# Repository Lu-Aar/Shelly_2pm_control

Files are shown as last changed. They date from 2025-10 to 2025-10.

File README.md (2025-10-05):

# Shelly_2pm_control

This piece of code is designed to be run on a ESP32 Super Mini.
It is able to search for a SHELLY 2PM by looking for its MAC address. It can then control certain features of it.

For now it's only able to:
- Raise the shutter
- Stop the shutter
- Close the shutter
- Put the shutter on ventilation when it's stopped

When checking out there is one file missing "config.h". This file must be created after checking out and it should contain the following two items:
```c
#define WIFI_SSID "THE_SSID_TO_CONNECT_TO"
#define WIFI_PASS "THE_PASSWORD_FOR_THAT_SSID"
```

## PCB
The PCB was created in KiCad. It's a free opensource program for creating schematics and PCB's.
https://www.kicad.org/

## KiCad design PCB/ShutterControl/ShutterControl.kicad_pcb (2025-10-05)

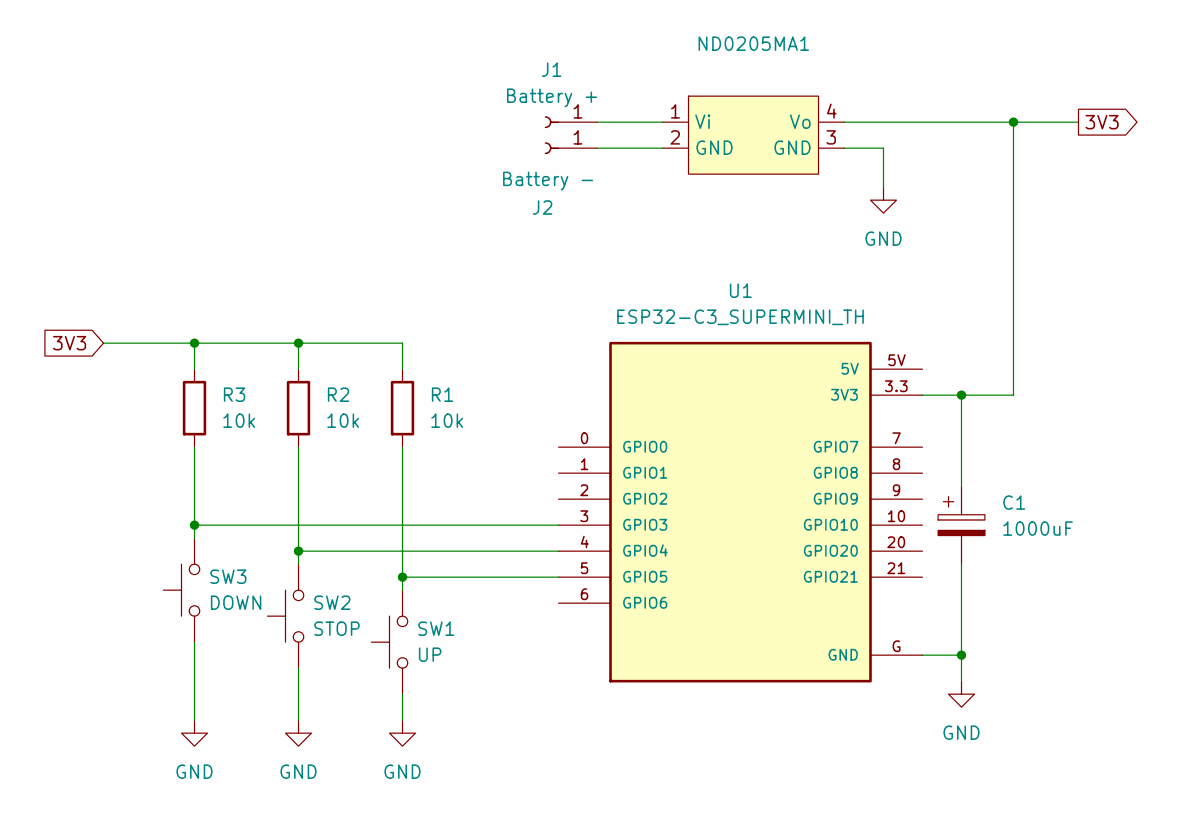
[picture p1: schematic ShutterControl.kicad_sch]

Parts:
C1: 1000uF; CP_Radial_D8.0mm_P3.50mm
J1: Battery +; TestPoint_THTPad_2.0x2.0mm_Drill1.0mm
J2: Battery -; TestPoint_THTPad_2.0x2.0mm_Drill1.0mm
ND0205MA1: ND0205MA
R1, R2, R3: 10k; R_Axial_DIN0204_L3.6mm_D1.6mm_P5.08mm_Horizontal
SW1: UP; SW_PUSH_6mm_H5mm
SW2: STOP; SW_PUSH_6mm_H5mm
SW3: DOWN; SW_PUSH_6mm_H5mm
U1: ESP32-C3_SUPERMINI_TH; MODULE_ESP32-C3_SUPERMINI_TH

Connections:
3V3: C1.1, ND0205MA1.4 (Vo), R1.1, R2.1, R3.1, U1.3.3 (3V3); also elsewhere on the board
GND: C1.2, ND0205MA1.3 (GND), SW1.1, SW2.1, SW3.1, U1.G (GND); also elsewhere on the board
unnamed 2: J1.1, ND0205MA1.1 (Vi); also elsewhere on the board
unnamed 3: J2.1, ND0205MA1.2 (GND); also elsewhere on the board
unnamed: R3.2, SW3.2, U1.3 (GPIO3)
unnamed: R2.2, SW2.2, U1.4 (GPIO4)
unnamed: R1.2, SW1.2, U1.5 (GPIO5)

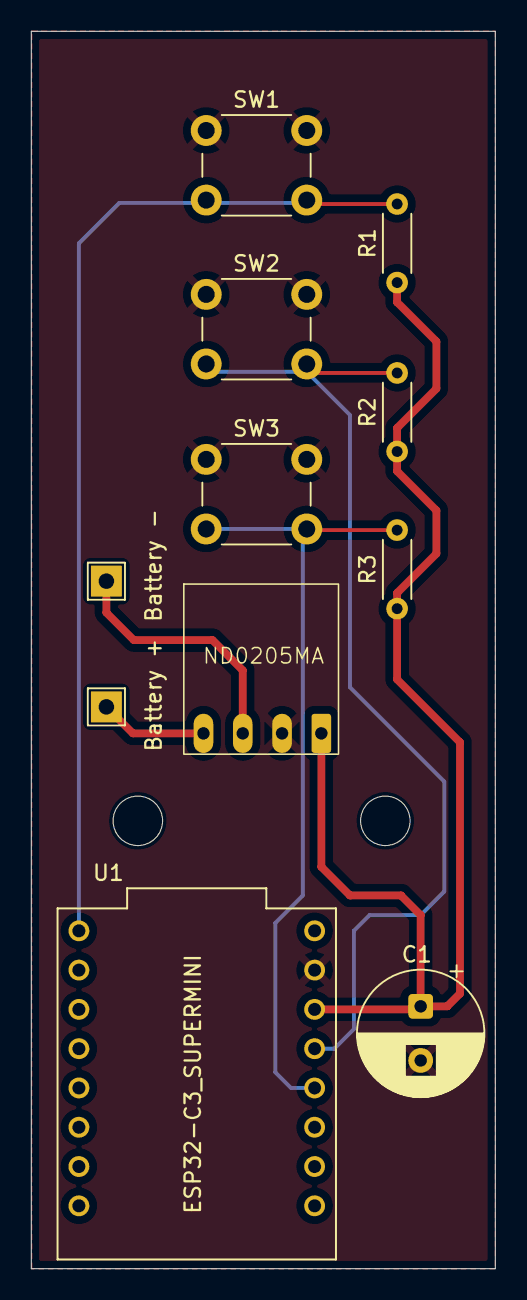
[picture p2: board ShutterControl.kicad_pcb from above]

Board: 2 copper layers, 30.0 x 80.0 mm, 11 parts (0 on the bottom side), 7 nets.

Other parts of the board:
ND0205MA: ND0205MA

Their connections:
3V3: ND0205MA.4 (Vo); also elsewhere on the board
GND: ND0205MA.3 (GND); also elsewhere on the board
unnamed 2: ND0205MA.1 (Vi); also elsewhere on the board
unnamed 3: ND0205MA.2 (GND); also elsewhere on the board

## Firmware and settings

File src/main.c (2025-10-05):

#include <string.h>
#include "esp_system.h"
#include "esp_wifi.h"
#include "esp_event.h"
#include "esp_log.h"
#include "esp_http_client.h"
#include "esp_sleep.h"
#include "esp_pm.h"
#include "nvs_flash.h"
#include "freertos/FreeRTOS.h"
#include "freertos/task.h"
#include "freertos/event_groups.h"
#include "lwip/etharp.h"
#include "lwip/ip_addr.h"
#include "lwip/netif.h"
#include "driver/gpio.h"
#include "soc/gpio_reg.h"
#include "soc/io_mux_reg.h"
#include "ShutterControl.h"
#include "config.h"

// #define DEBUG
struct netif *esp_netif_get_netif_impl(esp_netif_t *esp_netif);

#define ESP_MAXIMUM_RETRY 10

#define WIFI_CONNECTED_BIT BIT0
#define WIFI_FAIL_BIT BIT1
#define ESP_WIFI_SCAN_AUTH_MODE_THRESHOLD WIFI_AUTH_WPA2_PSK

#define START_IP 1
#define END_IP 254

#define BUTTON_UP GPIO_NUM_5
#define BUTTON_STOP GPIO_NUM_4
#define BUTTON_DOWN GPIO_NUM_3

#define MACSTR "%02x:%02x:%02x:%02x:%02x:%02x"

#define AWAKE_TIME_MS 20000

static EventGroupHandle_t s_wifi_event_group;
static int s_retry_num = 0;

const uint8_t SHUTTER_MAC_1[] = {0xE4, 0xB3, 0x23, 0x23, 0x4B, 0x1C};
const uint8_t SHUTTER_MAC_2[] = {0xE4, 0xB3, 0x23, 0x1F, 0xFA, 0xAC};

void init(void);

static void event_handler(void *arg, esp_event_base_t event_base,
                          int32_t event_id, void *event_data)
{
    if (event_base == WIFI_EVENT && event_id == WIFI_EVENT_STA_START)
    {
        esp_wifi_connect();
    }
    else if (event_base == WIFI_EVENT && event_id == WIFI_EVENT_STA_DISCONNECTED)
    {
        if (s_retry_num < ESP_MAXIMUM_RETRY)
        {
            esp_wifi_connect();
            s_retry_num++;
#ifdef DEBUG
            ESP_LOGI("WIFI", "retry to connect to the AP");
#endif
        }
        else
        {
            xEventGroupSetBits(s_wifi_event_group, WIFI_FAIL_BIT);
        }
#ifdef DEBUG
        ESP_LOGI("WIFI", "connect to the AP fail");
#endif
    }
    else if (event_base == IP_EVENT && event_id == IP_EVENT_STA_GOT_IP)
    {
        ip_event_got_ip_t *event = (ip_event_got_ip_t *)event_data;
#ifdef DEBUG
        ESP_LOGI("WIFI", "got ip:" IPSTR, IP2STR(&event->ip_info.ip));
#endif
        s_retry_num = 0;
        xEventGroupSetBits(s_wifi_event_group, WIFI_CONNECTED_BIT);
    }
}

void DisableUnusedPins(void)
{
    gpio_config_t io_conf_0 = {
        .intr_type = GPIO_INTR_DISABLE,
        .mode = GPIO_MODE_OUTPUT,
        .pin_bit_mask = (1ULL << GPIO_NUM_0),
    };
    gpio_config(&io_conf_0);
    gpio_set_level(GPIO_NUM_0, 0);

    gpio_config_t io_conf_rest = {
        .intr_type = GPIO_INTR_DISABLE,
        .mode = GPIO_MODE_INPUT,
        .pin_bit_mask = (1ULL << GPIO_NUM_1) |
                        (1ULL << GPIO_NUM_2) |
                        (1ULL << GPIO_NUM_6) |
                        (1ULL << GPIO_NUM_7) |
                        (1ULL << GPIO_NUM_8) |
                        (1ULL << GPIO_NUM_9) |
                        (1ULL << GPIO_NUM_10) |
                        (1ULL << GPIO_NUM_20) |
                        (1ULL << GPIO_NUM_21),
        .pull_up_en = GPIO_PULLUP_ENABLE,
        .pull_down_en = GPIO_PULLDOWN_DISABLE,
    };
    gpio_config(&io_conf_rest);
}

ip4_addr_t RequestIp(const uint8_t *shutter_mac)
{
    ip4_addr_t result_ip;
    IP4_ADDR(&result_ip, 255, 255, 255, 255);

    esp_netif_t *netif = esp_netif_get_handle_from_ifkey("WIFI_STA_DEF");
    esp_netif_ip_info_t ip_info;
    esp_netif_get_ip_info(netif, &ip_info);

    struct netif *lwip_netif = esp_netif_get_netif_impl(netif);

    for (int ii = START_IP; ii <= END_IP; ++ii)
    {
        ip4_addr_t target_ip;
        IP4_ADDR(&target_ip,
                 ip_info.ip.addr & 0xFF,
                 (ip_info.ip.addr >> 8) & 0xFF,
                 (ip_info.ip.addr >> 16) & 0xFF,
                 ii);

        if (etharp_request(lwip_netif, &target_ip) != ERR_OK)
        {
#ifdef DEBUG
            ESP_LOGI("SHUTTER", "etharp_request failed for IP: " IPSTR, IP2STR(&target_ip));
#endif
        }
        vTaskDelay(pdMS_TO_TICKS(50));

        if ((ii % 10 == 0) || (ii == END_IP - 1))
        {
            struct eth_addr *mac;
            struct netif *netif_out;
            ip4_addr_t *ip_out;

            for (int jj = 0; jj < 10; ++jj)
            {
                if (etharp_get_entry(jj, &ip_out, &netif_out, &mac))
                {
                    if (memcmp(mac->addr, shutter_mac, 6) == 0)
                    {
#ifdef DEBUG
                        ESP_LOGI("SHUTTER", "Found MAC: " MACSTR " for IP: " IPSTR,
                                 mac->addr[0], mac->addr[1], mac->addr[2], mac->addr[3], mac->addr[4], mac->addr[5], IP2STR(ip_out));
#endif
                        return *ip_out;
                        break;
                    }
                }
            }
        }
    }
    return result_ip;
}

void ESPSleep(void)
{
#ifdef DEBUG
    ESP_LOGI("SLEEP", "Going to sleep now");
#endif
    DisableUnusedPins();
    esp_wifi_stop();
    esp_wifi_deinit();
    esp_deep_sleep_start();
}

void setup_wakeup()
{
    const uint64_t wakeup_pins = 1 << BUTTON_UP | 1 << BUTTON_STOP | 1 << BUTTON_DOWN;
    esp_deep_sleep_enable_gpio_wakeup(wakeup_pins, ESP_GPIO_WAKEUP_GPIO_LOW);
}

void GetIps(ip4_addr_t *pShutter1_ip, ip4_addr_t *pShutter2_ip)
{
    nvs_handle_t handle;
    nvs_open("storage", NVS_READWRITE, &handle);
    esp_err_t err1 = nvs_get_u32(handle, "ip1", &pShutter1_ip->addr);
    esp_err_t err2 = nvs_get_u32(handle, "ip2", &pShutter2_ip->addr);
    if (err1 == ESP_ERR_NVS_NOT_FOUND)
    {
        *pShutter1_ip = RequestIp(SHUTTER_MAC_1);
        nvs_set_u32(handle, "ip1", pShutter1_ip->addr);
#ifdef DEBUG
        ESP_LOGI("NVM", "Saved shutter1 IP");
#endif
    }
    if (err2 == ESP_ERR_NVS_NOT_FOUND)
    {
        *pShutter2_ip = RequestIp(SHUTTER_MAC_2);
        nvs_set_u32(handle, "ip2", pShutter2_ip->addr);
#ifdef DEBUG
        ESP_LOGI("NVM", "Saved shutter2 IP");
#endif
    }
    if (err1 == ESP_ERR_NVS_NOT_FOUND || err2 == ESP_ERR_NVS_NOT_FOUND)
    {
        nvs_commit(handle);
    }
    nvs_close(handle);

#ifdef DEBUG
    ESP_LOGI("SHUTTER", "Shutter1 IP: " IPSTR, IP2STR(&shutter1_ip));
    ESP_LOGI("SHUTTER", "Shutter2 IP: " IPSTR, IP2STR(&shutter2_ip));
#endif
}

void SetIps(ip4_addr_t shutter1_ip, ip4_addr_t shutter2_ip)
{
    nvs_handle_t handle;
    nvs_open("storage", NVS_READWRITE, &handle);
    nvs_set_u32(handle, "ip1", shutter1_ip.addr);
    nvs_set_u32(handle, "ip2", shutter2_ip.addr);
    nvs_commit(handle);
    nvs_close(handle);

#ifdef DEBUG
    ESP_LOGI("SHUTTER", "Shutter1 IP: " IPSTR, IP2STR(&shutter1_ip));
    ESP_LOGI("SHUTTER", "Shutter2 IP: " IPSTR, IP2STR(&shutter2_ip));
#endif
}

void Open(ip4_addr_t ip1, ip4_addr_t ip2)
{
    OpenShutter(ip1);
    OpenShutter(ip2);
}

void Stop(ip4_addr_t ip1, ip4_addr_t ip2)
{
    enum ShutterStatus state1 = GetShutterStatus(ip1);
    enum ShutterStatus state2 = GetShutterStatus(ip2);
#ifdef DEBUG
    ESP_LOGI("STATUS", "The shutter status is: %d", state1);
    ESP_LOGI("STATUS", "The shutter status is: %d", state2);
#endif
    if (state1 == SHUTTER_STATUS_OPENING || state1 == SHUTTER_STATUS_CLOSING)
    {
        StopShutter(ip1);
    }
    else if (state1 == SHUTTER_STATUS_STOPPED || state1 == SHUTTER_STATUS_OPEN || state1 == SHUTTER_STATUS_CLOSED)
    {
        SetShutterPosition(ip1, SHUTTER_VENTILATION);
    }

    if (state2 == SHUTTER_STATUS_OPENING || state2 == SHUTTER_STATUS_CLOSING)
    {
        StopShutter(ip2);
    }
    else if (state2 == SHUTTER_STATUS_STOPPED || state2 == SHUTTER_STATUS_OPEN || state2 == SHUTTER_STATUS_CLOSED)
    {
        SetShutterPosition(ip2, SHUTTER_VENTILATION);
    }
}

void Close(ip4_addr_t ip1, ip4_addr_t ip2)
{
    CloseShutter(ip1);
    CloseShutter(ip2);
}

void app_main()
{
    int gpioStates = REG_READ(GPIO_IN_REG);
    int buttonUpState = !((gpioStates >> BUTTON_UP) & 1);
    int buttonStopState = !((gpioStates >> BUTTON_STOP) & 1);
    int buttonDownState = !((gpioStates >> BUTTON_DOWN) & 1);
    init();
#ifdef DEBUG
    ESP_LOGI("BUTTON", "Button UP state: %d", buttonUpState);
    ESP_LOGI("BUTTON", "Button STOP state: %d", buttonStopState);
    ESP_LOGI("BUTTON", "Button DOWN state: %d", buttonDownState);
#endif

    gpio_config_t io_conf = {
        .intr_type = GPIO_INTR_DISABLE,
        .mode = GPIO_MODE_INPUT,
        .pin_bit_mask = (1ULL << BUTTON_UP) | (1ULL << BUTTON_STOP) | (1ULL << BUTTON_DOWN),
    };
    gpio_config(&io_conf);
    setup_wakeup();

    ip4_addr_t shutter1_ip;
    ip4_addr_t shutter2_ip;
    GetIps(&shutter1_ip, &shutter2_ip);

    const TickType_t awake_time = pdMS_TO_TICKS(AWAKE_TIME_MS);
    TickType_t last_wake = xTaskGetTickCount();

    while (1)
    {
        if (!buttonUpState && !buttonStopState && !buttonDownState)
        {
            gpioStates = REG_READ(GPIO_IN_REG);
            buttonUpState = !((gpioStates >> BUTTON_UP) & 1);
            buttonStopState = !((gpioStates >> BUTTON_STOP) & 1);
            buttonDownState = !((gpioStates >> BUTTON_DOWN) & 1);
        }
        if (buttonUpState || buttonStopState || buttonDownState)
        {
            last_wake = xTaskGetTickCount();
        }

        if ((xTaskGetTickCount() - last_wake) > awake_time)
        {
            ESPSleep();
        }

        if (buttonUpState && buttonDownState)
        {
            shutter1_ip = RequestIp(SHUTTER_MAC_1);
            shutter2_ip = RequestIp(SHUTTER_MAC_2);
            SetIps(shutter1_ip, shutter2_ip);

            buttonUpState = 0;
            buttonDownState = 0;
        }
        else
        {
            if (buttonUpState)
            {
                Open(shutter1_ip, shutter2_ip);
                buttonUpState = 0;
            }
            if (buttonStopState)
            {
                Stop(shutter1_ip, shutter2_ip);
                buttonStopState = 0;
            }
            if (buttonDownState)
            {
                Close(shutter1_ip, shutter2_ip);
                buttonDownState = 0;
            }
        }
        vTaskDelay(pdMS_TO_TICKS(10));
    }
}

void wifi_init_sta(void)
{
    s_wifi_event_group = xEventGroupCreate();

    ESP_ERROR_CHECK(esp_netif_init());

    ESP_ERROR_CHECK(esp_event_loop_create_default());
    esp_netif_create_default_wifi_sta();

    wifi_init_config_t cfg = WIFI_INIT_CONFIG_DEFAULT();
    ESP_ERROR_CHECK(esp_wifi_init(&cfg));

    esp_event_handler_instance_t instance_any_id;
    esp_event_handler_instance_t instance_got_ip;
    ESP_ERROR_CHECK(esp_event_handler_instance_register(WIFI_EVENT,
                                                        ESP_EVENT_ANY_ID,
                                                        &event_handler,
                                                        NULL,
                                                        &instance_any_id));
    ESP_ERROR_CHECK(esp_event_handler_instance_register(IP_EVENT,
                                                        IP_EVENT_STA_GOT_IP,
                                                        &event_handler,
                                                        NULL,
                                                        &instance_got_ip));

    wifi_config_t wifi_config = {
        .sta = {
            .ssid = WIFI_SSID,
            .password = WIFI_PASS},
    };
    ESP_ERROR_CHECK(esp_wifi_set_mode(WIFI_MODE_STA));
    ESP_ERROR_CHECK(esp_wifi_set_config(WIFI_IF_STA, &wifi_config));
    ESP_ERROR_CHECK(esp_wifi_start());
    esp_wifi_connect();

    EventBits_t bits = xEventGroupWaitBits(s_wifi_event_group,
                                           WIFI_CONNECTED_BIT | WIFI_FAIL_BIT,
                                           pdFALSE,
                                           pdFALSE,
                                           portMAX_DELAY);

#ifdef DEBUG
    ESP_LOGI("WIFI", "wifi_init_sta finished.");
    if (bits & WIFI_CONNECTED_BIT)
    {
        ESP_LOGI("WIFI", "connected to ap SSID:%s",
                 WIFI_SSID);
    }
    else if (bits & WIFI_FAIL_BIT)
    {
        ESP_LOGI("WIFI", "Failed to connect to SSID:%s",
                 WIFI_SSID);
    }
    else
    {
        ESP_LOGE("WIFI", "UNEXPECTED EVENT");
    }
#endif
}

void init()
{
    esp_err_t ret = nvs_flash_init();

    if (ret == ESP_ERR_NVS_NO_FREE_PAGES || ret == ESP_ERR_NVS_NEW_VERSION_FOUND)
    {
        ESP_ERROR_CHECK(nvs_flash_erase());
        ret = nvs_flash_init();
    }
    ESP_ERROR_CHECK(ret);

#ifdef DEBUG
    if (CONFIG_LOG_MAXIMUM_LEVEL > CONFIG_LOG_DEFAULT_LEVEL)
    {
        esp_log_level_set("wifi", CONFIG_LOG_MAXIMUM_LEVEL);
    }
    ESP_LOGI("WIFI", "ESP_WIFI_MODE_STA");
#endif
    wifi_init_sta();
}

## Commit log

2025-08-15 Created a PCB
    [PlugControl.kicad_pcb, PlugControl.kicad_sch]
2025-08-19 Solved an error with committing
    [PlugControl.kicad_pcb, ShutterControl.kicad_pcb, ShutterControl.kicad_sch]
2025-08-24 Changed from light to deep sleep. Can't get the power consumption from the PCB lower than 0.5mA in deep sleep.
